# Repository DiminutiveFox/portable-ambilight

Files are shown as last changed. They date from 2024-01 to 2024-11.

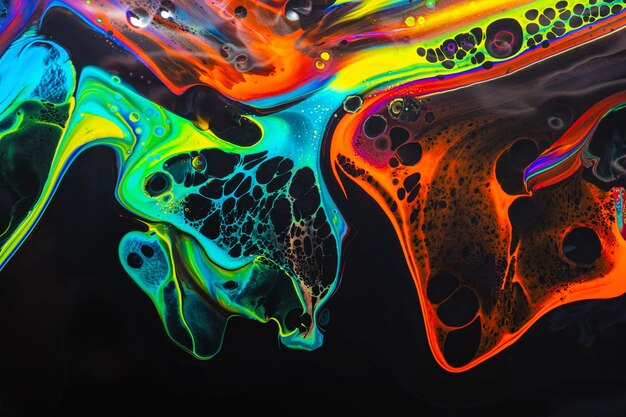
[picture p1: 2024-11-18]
test_pictures/vivid-colors-abstract-background-bright-trending-colors-palette-pattern_568886-6848.jpg

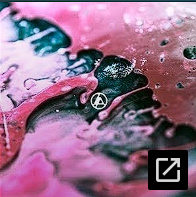
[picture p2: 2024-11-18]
test_pictures/picture2.png

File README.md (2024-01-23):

# Portable Ambilight
Prototype of custom portable ambilight solution made of 3d printed parts, ESP32-C3 development board and WS2812B LED strip.
It is meant for laptops' screens and has a few interesting traits:
- it can be easily removed from the back of the screen
- comunicates with system over USB
- is customizable
- easy to use
- WS2812B does not need to be externally powered up

Ambilight

# Project description
Project's code is entirely written in python. It has 3 files - 2 of them are meant for ESP32-C3 (boot.py and esp_main.py). To be able to run python code on this module you first need to install micropython on it. There are several tutorials all over the internet that show the process and also how to flash the board. Need to know that different ESP development boards can be used, but installation of micropython might vary depending on the module. Micropython might not be the right choice for this kind of project but I wanted to show that this task is doable using it. 

# Way of communication
The goal is to communicate and send all the needed data through USB. It rises a few challanges since serial communication is not suitable choice for video stream - it's too slow. Message sent to ESP needs to be as short as possible to keep LEDs frame's framerate around 20-30fps. It provides the best experience. File main.py needs to be run in the background - it takes screnshot of the areas near the screen's sides and extracts RGB values for LEDs to display. The value depends on the function applied for the extracted area - at this moment only 'average' function is available - more will be added in the future. Message's length depends mostly on how many LEDs are in the setup - in my case there are 72 LEDs - 36 on the upper frame, 18 LEDs for each side. Value for every RGB LED is scaled down (scale parameter set to 1) from 0-255 to 0-99 range - it shortens a message a bit and the result is indistinguishable comparing to not scaled down message. Additionally user can specify how many LEDs light up e.g. every second or third LED (led_span parameter). Below is a example of message combined of scaled LEDs' values.



Framerate also depends on the screen resolution - the higher the resolution the more it takes to create a screenshot and compute LEDs' values. Also compute power of your PC is relevant - code is much slower on older machines.  

# main.py
The heart of the project - it's functionality was mostly described above. User needs to specify parameters of the setup e.g. number of LEDs and screen resolution (all parameters are found in __main__). On PC side we use UART for communication. Using baudrate above 115200 is not recommended.



# boot.py
This is the file which is executed when ESP boots. It has standard structure and executes main.py which contains all important functions. Read the comments to configure the esp startup. Starting main loop from REPL is though recommended. Remember when esp_main.main() is started directly in boot.py file the REPL is lost and all files need to be erased (for example using esptool) to be able to flash ESP again.

# esp_main.py
This is the main file for ESP. The most important aspect is that we want to communicate with system over USB-TTL bridge already mounted on board. It cannot be done easily since this bridge is connected to the UART0 which is reserved for REPL. Instead of UART communication sys.stdin is used for message reading on the ESP side. Default baudrate for REPL is 115200. It can be increased but communication becames unpredictable in higher rates - sometimes message is not read entirely or new message is inserted in the middle of the previous one. ESP behavior highly depends on the module. Check manufacturer's docs before buying one (and avoid my rookie mistake). Specify number of LEDs and GPIO for NeoPixel object. For debugging purpose you can uncomment part of code which sends the message back to the PC (also you need to do this in main.py file) 



# 3d parts 
LED strip (if you are using standard monitor) can be attached directly to the back of your screen. But if you are using laptop (like me) you might want to use your ambilight only when you are home and remove it when travelling. So that is why I made a 3d printed frame that can be attached to the back using suction cups. All parts (apart of suction cups) are provided in the project. Mind that ESP case might not be suitable for your dev board. This design might not be the best (in my humble opinion it is even ugly and there is a lot of space for improvement) but it provides all functionality that is needed. Frame is combined out of 4 parts - 2 side frames, upper frame and base frame. I recommend to glue everything together. Insert suction cups into the holes in side frames. Put ESP in case and glue it into the base. LED strip is glued to the sides of the frame (picture below).



# Step by step guide

- download and print 3d parts - you can of course make your own design
- glue everything together
- put suction cups into the holes
- cut and solder LED strip accordingly to the picture below
- setup your ESP (useful commands can be found in HandyEsptoolCommands file) and run esp_main.main()
- specify parameters of your setup in main.py file and run it
- put it on the back on your laptop
- enjoy!



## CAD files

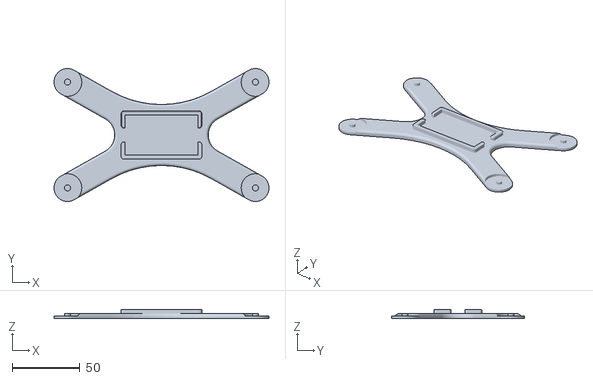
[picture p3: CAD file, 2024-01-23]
3d_parts/BaseFrame.stl
158.6 x 98.1 x 7.00

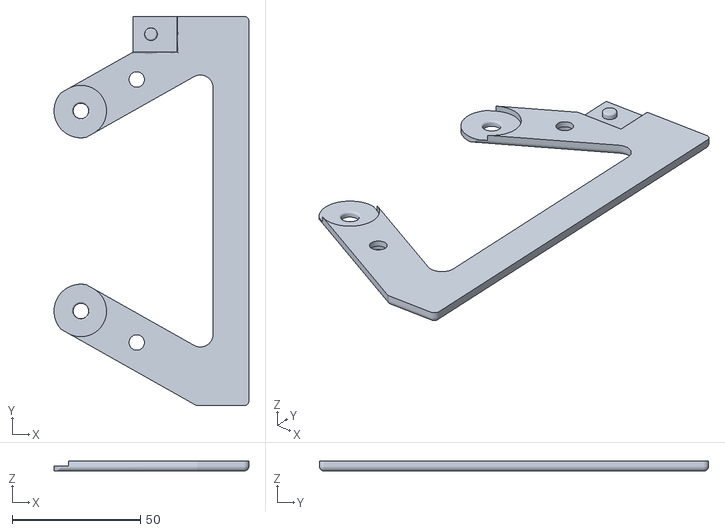
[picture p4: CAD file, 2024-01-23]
3d_parts/LeftSideFrame.stl
76.1 x 151.9 x 3.95

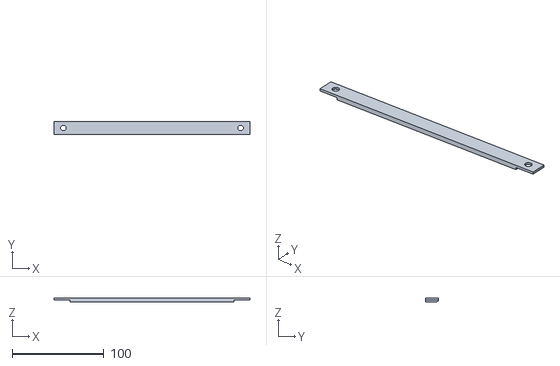
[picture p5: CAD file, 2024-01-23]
3d_parts/UpperFrame.stl
213.8 x 14.0 x 4.00

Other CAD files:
3d_parts/esp_case.stl
3d_parts/RightSideFrame.stl

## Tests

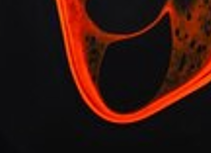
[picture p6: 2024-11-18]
test_pictures/test1.png

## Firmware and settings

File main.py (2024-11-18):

import tkinter as tk
from tkinter import messagebox, ttk
import threading
import cv2
import numpy as np
import serial
import time
from collections import Counter
import mss
import serial.tools.list_ports

# Global variable to control the running state of the serial communication thread
running = True

def is_vivid_color(pixel, threshold=30):
    r, g, b = pixel
    if max(abs(r - g), abs(g - b), abs(b - r)) > threshold:
        return True
    return False

def dominant_color(screenshot, k=5):
    
    # Reshape the image to a list of pixels
    pixels = screenshot.reshape((-1, 3))
    pixels = np.float32(pixels)

    # Filter out grayscale pixels
    vivid_pixels = np.array([pixel for pixel in pixels if is_vivid_color(pixel)])
    
    if len(vivid_pixels) == 0:
        return None  # No vivid colors found

    # Define k-means criteria
    criteria = (cv2.TERM_CRITERIA_EPS + cv2.TERM_CRITERIA_MAX_ITER, 100, 0.2)
    
    # Apply k-means clustering
    _, labels, centers = cv2.kmeans(vivid_pixels, k, None, criteria, 10, cv2.KMEANS_RANDOM_CENTERS)
    centers = np.uint8(centers)
    
    # Find the most vivid color (with maximum saturation)
    vivid_color = max(centers, key=lambda c: np.std(c))

    return vivid_color

def average_color(image):
    """
    Returns average color of the image
    :param image:           NumPy array
    :return:                Average pixel value of a specified field
    """
    return np.average(image, axis=(1, 0))

def color_extraction(image_list, color_func, scale, led_number, use_constant_color=False, constant_color=None):
    if use_constant_color and constant_color:
        color_list = [constant_color for _ in range(led_number)]
    else:
        color_list = [color_func(image_list[n]) for n in range(led_number)]
    if scale:
        color_list = [[str(scale_channel(channels[2])), str(scale_channel(channels[1])),
                       str(scale_channel(channels[0]))] for channels in color_list]
    else:
        color_list = [[str(int(channels[2])), str(int(channels[1])), str(int(channels[0]))] for channels in color_list]

    return color_string(color_list, scale)

def scale_channel(channel_value):
    """
    Scales down channel value from range 0-255 to 0-99
    :param      channel_value: color channel
    :return:    Scaled channel value
    """
    channel_max_value = 255
    channel_scaled_max_value = 99
    ret_val = channel_value * channel_scaled_max_value / channel_max_value
    if ret_val > 99:
        ret_val = 99
    return int(ret_val)

def color_string(color_list, scale):
    """
    Returns color string completed with redundant zeros.
    As a result output string for esp32 has the same length every time.
    :param color_list:  list of colors extracted in previous steps
    :param scale:       parameter that specifies if color scale is reduced from 0-255 to 0-99
    :return:            Color string
    """

    channel_length = 2 if scale else 3
    for color in color_list:
        while len(color[0]) < channel_length:
            color[0] = '0' + color[0]
        while len(color[1]) < channel_length:
            color[1] = '0' + color[1]
        while len(color[2]) < channel_length:
            color[2] = '0' + color[2]
    return ''.join([''.join(sublist) for sublist in color_list])


def color_gen(scale=True, led_span=1, h_leds=18, w_leds=36, h=1440, w=2560):
    """
    Returns color spectrum of a display's frame
    :param scale:       parameter that specifies if color scale is reduced from 0-255 to 0-99
    :param led_span:    reduces the number of active WS2812B LEDS (1, 2, 3)
    :param h_leds:      number of leds on side frame
    :param w_leds:      number of leds on upper frame
    :param h:           number of rows of pixels for screen resolution
    :param w:           number of columns of pixels for screen resolution
    :return:            Color string
    """

    # For performance measurement purpose
def color_gen(scale=True, led_span=1, h_leds=18, w_leds=36, h=1440, w=2560, use_constant_color=False, constant_color=None, method=average_color):
    s_time = time.time()
    led_span = 1 if led_span not in [1, 2, 3] else led_span
    h_leds = int(h_leds / led_span)
    w_leds = int(w_leds / led_span)
    h_divider = 8
    w_divider = 16

    u_box = {"top": 0, "left": 0, "width": w, "height": int(h / h_divider)}
    l_box = {"top": int(h / h_divider), "left": 0, "width": int(w / w_divider), "height": int(h - h / h_divider)}
    r_box = {"top": int(h / h_divider), "left": int(w - w / w_divider),
             "width": int(w / w_divider), "height": int(h - h / h_divider)}

    with mss.mss() as camera:
        u_screenshot = np.array(camera.grab(u_box))
        l_screenshot = np.array(camera.grab(l_box))
        r_screenshot = np.array(camera.grab(r_box))
        u_screenshot = cv2.resize(u_screenshot, dsize=(int(w/4), int(h/h_divider/4)), interpolation=cv2.INTER_NEAREST)
        l_screenshot = cv2.resize(l_screenshot, dsize=(int(h/4), int(w/w_divider/4)), interpolation=cv2.INTER_NEAREST)
        r_screenshot = cv2.resize(r_screenshot, dsize=(int(h/4), int(w/w_divider/4)), interpolation=cv2.INTER_NEAREST)

    print(f"Time of taking screenshot: {time.time() - s_time}")

    h_r, w_r, c_r = r_screenshot.shape
    h_l, w_l, c_l = l_screenshot.shape
    h_u, w_u, c_u = u_screenshot.shape

    l_image_list = [l_screenshot[int(n*h_l/h_leds):int(n*h_l/h_leds+h_l/h_leds):] for n in range(h_leds - 1, -1, -1)]
    l_colors = color_extraction(l_image_list, method, scale, h_leds, use_constant_color, constant_color)

    u_image_list = [u_screenshot[:, int(n * w_u / w_leds):int(n * w_u / w_leds + w_u / w_leds)] for n in range(w_leds)]
    u_colors = color_extraction(u_image_list, method, scale, w_leds, use_constant_color, constant_color)

    r_image_list = [r_screenshot[int(n * h_r / h_leds):int(n * h_r / h_leds + h_r / h_leds), :] for n in range(h_leds)]
    r_colors = color_extraction(r_image_list, method, scale, h_leds, use_constant_color, constant_color)

    print(f"Time of color extraction: {time.time() - s_time}")
    return l_colors + u_colors + r_colors

    # Configure the serial port
def serial_comm(port, baudrate, scale=1, led_span=2, h_leds=18, w_leds=36, h=1440, w=2560, use_constant_color=False, constant_color=None, method='average'):
    """
    Exchanges data between device via serial port
    :param port:        ESP port
    :param baudrate:    ESP communication baudrate (115200 default - other might be unstable)
    :param scale:       parameter that specifies if color scale is reduced from 0-255 to 0-99
    :param              led_span: reduces the number of active WS2812B LEDS (1, 2, 3)
    :param              h_leds: number of leds on the side frame
    :param              w_leds: number of leds on the upper frame
    :param h:           number of rows of pixels for screen resolution
    :param w:           number of columns of pixels for screen resolution
    :return:            Nothing
    """
    ser = serial.Serial()
    ser.setDTR(False)
    ser.setRTS(False)
    ser.port = port
    ser.baudrate = baudrate
    ser.open()
    # ser.timeout = 0.001
    
    color_extract_mehod = average_color if method == 'average' else dominant_color

    try:
        while running:  # Check if the thread should keep running
            start_time = time.time()

            # Send a message (2 first characters are meant for led strip configuration)
            # message = str(scale) + str(led_span) + color_gen(scale=bool(scale), led_span=led_span,
            #                                                  h_leds=h_leds, w_leds=w_leds, h=h, w=w) + '\n'
            color_str = f"{constant_color[0]},{constant_color[1]},{constant_color[2]}" if use_constant_color and constant_color else "0,0,0"
            color_string = color_gen(scale=bool(scale), led_span=led_span,
                                                             h_leds=h_leds, w_leds=w_leds, h=h, w=w, use_constant_color=use_constant_color, constant_color=constant_color, method=color_extract_mehod)
            message = str(scale) + str(led_span) + color_string + '\n'
            ser.write(message.encode('utf-8'))
            print(message)
            time.sleep(0.01) if led_span == 1 else None
            end_time = time.time()
            print(f'Time elapsed: {end_time - start_time}')

    except KeyboardInterrupt:
        ser.close()
    finally:
        ser.close()  # Ensure the serial connection is closed when exiting

def find_port(device_name):
    """
    Finds port of specified device
    :param device_name:     Device's name (can be found in device manager)
    :return:                Port's name
    """

    ports = list(serial.tools.list_ports.comports())
    for port, desc, hwid in ports:
        if device_name.lower() in desc.lower():
            return port

def start_serial_comm(scale, led_span, h_leds, w_leds, h, w, use_constant_color, constant_color, method):
    global running
    ESP32_name = 'CH340'

    # Specify the baudrate for UART communication - 115200 most stable
    ESP32_baudrate = 115200
    # ESP32_baudrate = 230400
    # Find port of specified module
    ESP32_port = find_port(ESP32_name)

    # Start communication
    serial_comm(ESP32_port, ESP32_baudrate, scale, led_span, h_leds, w_leds, h, w) if ESP32_port else \
        print("Specified device not found!")
    if ESP32_port:
        running = True  # Reset the running flag to True
        serial_comm(ESP32_port, ESP32_baudrate, scale, led_span, h_leds, w_leds, h, w, use_constant_color, constant_color, method)
    else:
        print("Specified device not found!")

def start_thread(scale, led_span, h_leds, w_leds, h, w, use_constant_color, constant_color, method):
    global running
    threading.Thread(target=start_serial_comm, args=(scale, led_span, h_leds, w_leds, h, w, use_constant_color, constant_color, method), daemon=True).start()

def start_button_clicked():
    try:
        scale = int(scale_entry.get())
        led_span = int(led_span_entry.get())
        h_leds = int(h_leds_entry.get())
        w_leds = int(w_leds_entry.get())
        h = int(h_entry.get())
        w = int(w_entry.get())
        r = int(r_entry.get())
        g = int(g_entry.get())
        b = int(b_entry.get())
        constant_color = (r, g, b)
        method = extraction_method_combobox.get()
        use_constant_color = send_constant_color_var.get() == 1

        start_thread(scale, led_span, h_leds, w_leds, h, w, use_constant_color, constant_color, method)

    except ValueError as e:
        messagebox.showerror("Invalid input", str(e))

def stop_button_clicked():
    global running
    running = False  # Set the running flag to False to stop the thread

root = tk.Tk()
root.title("Color Extraction")

main_frame = ttk.Frame(root, padding="10")
main_frame.grid(row=0, column=0, sticky=(tk.W, tk.E, tk.N, tk.S))

# Create and place the input fields and labels
scale_label = ttk.Label(main_frame, text="Scale (0 or 1):")
scale_label.grid(row=0, column=0, sticky=tk.W)
scale_entry = ttk.Entry(main_frame)
scale_entry.grid(row=0, column=1)

led_span_label = ttk.Label(main_frame, text="LED Span (1, 2, or 3):")
led_span_label.grid(row=1, column=0, sticky=tk.W)
led_span_entry = ttk.Entry(main_frame)
led_span_entry.grid(row=1, column=1)

h_leds_label = ttk.Label(main_frame, text="Horizontal LEDs:")
h_leds_label.grid(row=2, column=0, sticky=tk.W)
h_leds_entry = ttk.Entry(main_frame)
h_leds_entry.grid(row=2, column=1)

w_leds_label = ttk.Label(main_frame, text="Vertical LEDs:")
w_leds_label.grid(row=3, column=0, sticky=tk.W)
w_leds_entry = ttk.Entry(main_frame)
w_leds_entry.grid(row=3, column=1)

h_label = ttk.Label(main_frame, text="Screen Height:")
h_label.grid(row=4, column=0, sticky=tk.W)
h_entry = ttk.Entry(main_frame)
h_entry.grid(row=4, column=1)

w_label = ttk.Label(main_frame, text="Screen Width:")
w_label.grid(row=5, column=0, sticky=tk.W)
w_entry = ttk.Entry(main_frame)
w_entry.grid(row=5, column=1)

r_label = ttk.Label(main_frame, text="Blue Value (0-255):")
r_label.grid(row=6, column=0, sticky=tk.W)
r_entry = ttk.Entry(main_frame)
r_entry.grid(row=6, column=1)

g_label = ttk.Label(main_frame, text="Green Value (0-255):")
g_label.grid(row=7, column=0, sticky=tk.W)
g_entry = ttk.Entry(main_frame)
g_entry.grid(row=7, column=1)

b_label = ttk.Label(main_frame, text="Red Value (0-255):")
b_label.grid(row=8, column=0, sticky=tk.W)
b_entry = ttk.Entry(main_frame)
b_entry.grid(row=8, column=1)

# Method selection
extraction_method_label = ttk.Label(main_frame, text="Extraction Method:")
extraction_method_label.grid(row=9, column=0, sticky=tk.W)
extraction_method_combobox = ttk.Combobox(main_frame, values=["average", "dominant"])
extraction_method_combobox.grid(row=9, column=1)

# Checkbox for sending constant color
send_constant_color_var = tk.IntVar()
send_constant_color_check = ttk.Checkbutton(main_frame, text="Send Constant Color", variable=send_constant_color_var)
send_constant_color_check.grid(row=10, column=0, columnspan=2)

# Default values
DEFAULT_SCALE = 1
DEFAULT_LED_SPAN = 2
DEFAULT_H_LEDS = 18
DEFAULT_W_LEDS = 32
DEFAULT_H = 1440
DEFAULT_W = 2560
DEFAULT_R = 0
DEFAULT_G = 0
DEFAULT_B = 0
DEFAULT_METHOD = "average"

# Set default values in the entry fields
scale_entry.insert(0, DEFAULT_SCALE)
led_span_entry.insert(0, DEFAULT_LED_SPAN)
h_leds_entry.insert(0, DEFAULT_H_LEDS)
w_leds_entry.insert(0, DEFAULT_W_LEDS)
h_entry.insert(0, DEFAULT_H)
w_entry.insert(0, DEFAULT_W)
r_entry.insert(0, DEFAULT_R)
g_entry.insert(0, DEFAULT_G)
b_entry.insert(0, DEFAULT_B)
extraction_method_combobox.set(DEFAULT_METHOD)

start_button = ttk.Button(main_frame, text="Start", command=start_button_clicked)
start_button.grid(row=11, column=0, columnspan=2, pady=5)

stop_button = ttk.Button(main_frame, text="Stop", command=stop_button_clicked)
stop_button.grid(row=12, column=0, columnspan=2, pady=5)

root.mainloop()

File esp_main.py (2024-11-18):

import sys
import uselect
from machine import Pin
import machine
import neopixel
import json
import time


# Total number of LEDs
NUM_PIXELS = 72

# Configure the Neopixel
NEO_PIN = 5  # GPIO for neopixel data

# NeoPixel configuration
np = neopixel.NeoPixel(Pin(NEO_PIN), NUM_PIXELS)

# Serial port configuration - only way to communicate thought USB
serialPoll = uselect.poll()
serialPoll.register(sys.stdin, uselect.POLLIN)


def convert_to_list(color_string):
    """Converts received string of colors to list"""
    return json.loads(color_string)


def handle_command(command):
    """Returns command to the stream"""
    if command:
        sys.stdout.buffer.write(command)


def create_ambience(color_string, scale=True, led_span=1):
    """
    Converts message to list of colors and writes it to NeoPixel instance \n \n
    Arguments: \n
    scale:            determines if color scale is reduced from 0-255 to 0-99
    channel_length:   length of the channel string (3 by default, 2 if scale is used)\n
    led_span:         reduces the number of active WS2812B LEDS
    """

    color_length = 6 if scale else 9
    channel_length = 2 if scale else 3

    color_strings = [color_string[i:i + color_length] for i in range(0, len(color_string), color_length)]

    if scale:
        color_list = [[scale_channel(int(color[i:i + channel_length])) for i in range(0, len(color), channel_length)]
                      for color in color_strings]
    else:
        color_list = [[int(color[i:i + channel_length]) for i in range(0, len(color), channel_length)]
                      for color in color_strings]

    # print(len(color_list))
    for i, color in enumerate(color_list):
        np[led_span * i] = color if len(color) == 3 else [0, 0, 0]
    np.write()


def scale_channel(channel_value):
    """
    Scales channel value back to original values (not accurately)
    :param channel_value: channel value in scale 0-99
    :return:
    """

    channel_max_value = 99
    channel_scaled_max_value = 255

    return int(channel_value*channel_scaled_max_value/channel_max_value)


def reset_np():
    """
    Resets all pixel values back to [0, 0, 0]
    :return:
    """
    for i in range(NUM_PIXELS):
        np[i] = [0, 0, 0]
    np.write()


def read_serial():
    """
    Reads a message - 5216 is the longest
    :return: message (in bytes)
    """

    return sys.stdin.buffer.readline(5216) if serialPoll.poll(10) else None


def serial_comm(baudrate=115200):
    """

    :param baudrate:
    :return:
    """
    #Changing baudrate
    if baudrate != 115200:
        machine.UART(0, baudrate=baudrate)

    config_mem = []

    # Main communication loop
    while True:
        try:
            data = read_serial()
            if data is not None:
                data = data.decode('utf-8').strip('\n')
                print(data)
                config = list(data[:2])
                color_string = data[2:]
                if config_mem != config:
                    reset_np()
                    # print('reset')
                else:
                    create_ambience(color_string, bool(config[0]), int(config[1]))
                # print(data)
                config_mem = config
        except Exception as err:
            print(err)
            pass


def main():

    print("Entering main...")
    time.sleep(0.5)
    esp32_baudrate = 230400
    # esp32_baudrate = 460800
    serial_comm(esp32_baudrate)
